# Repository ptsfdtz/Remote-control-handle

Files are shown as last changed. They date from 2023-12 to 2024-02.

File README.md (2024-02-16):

# Remote-control-handle

基于 nRF24L01 模块的远距离通讯以及遥控

## 1. 项目介绍

本项目是 2.4G 远距离遥控器的制作，基于 `Arduino` 框架开发

模型使用的是`soildworks`制作。

## 2. 项目结构

- **code** 代码
- **lib** 库
- **part** 模型部件
- **assembly** 模型装配体
- **stl** 打印模型

## 3. 模型介绍

模型灵感来源于在 Youtube 上看到一位博主自制的遥控器，比较感兴趣，所以参考了一下他的模型

有兴趣的可以去看一看这个视频，链接如下

[Making a 2400 meters LONG RANGE 8-Channel & Digital Trim Radio Control For RC Models](https://www.youtube.com/watch?v=RSDfMaanKXM&list=WL)

### 3.1 模型设计思路

为了更加贴切于航模遥控器和满足人体工程学，制作的还是最简单的盒子式的遥控器。

也是为了方便后期电路的布局不允许正常布线，模型制作的比较简单。

应各位同仁爱好，使用主题颜色使用的粉色和灰色，更加符合我们技术部的猛男特色。

### 3.2 模型视图

- #### 整体视图

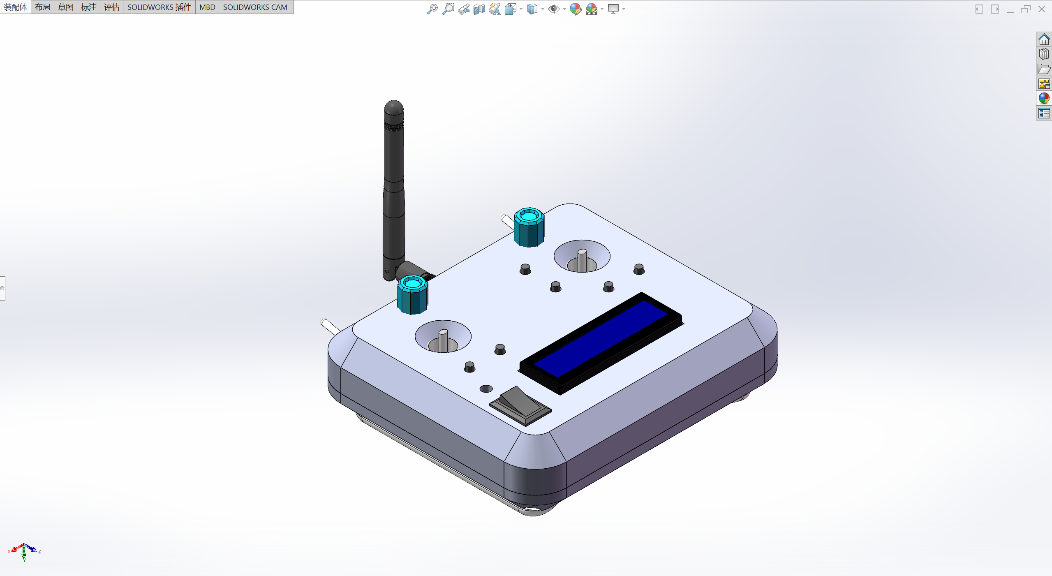
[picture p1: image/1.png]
整体视图


- #### 正面视图

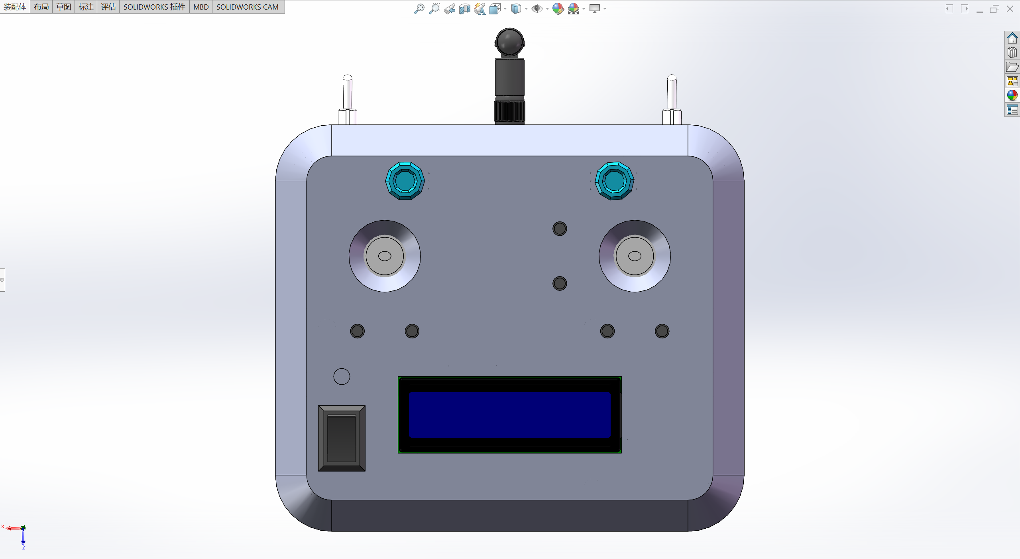
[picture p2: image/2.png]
正面视图


- #### 背面视图（透视）

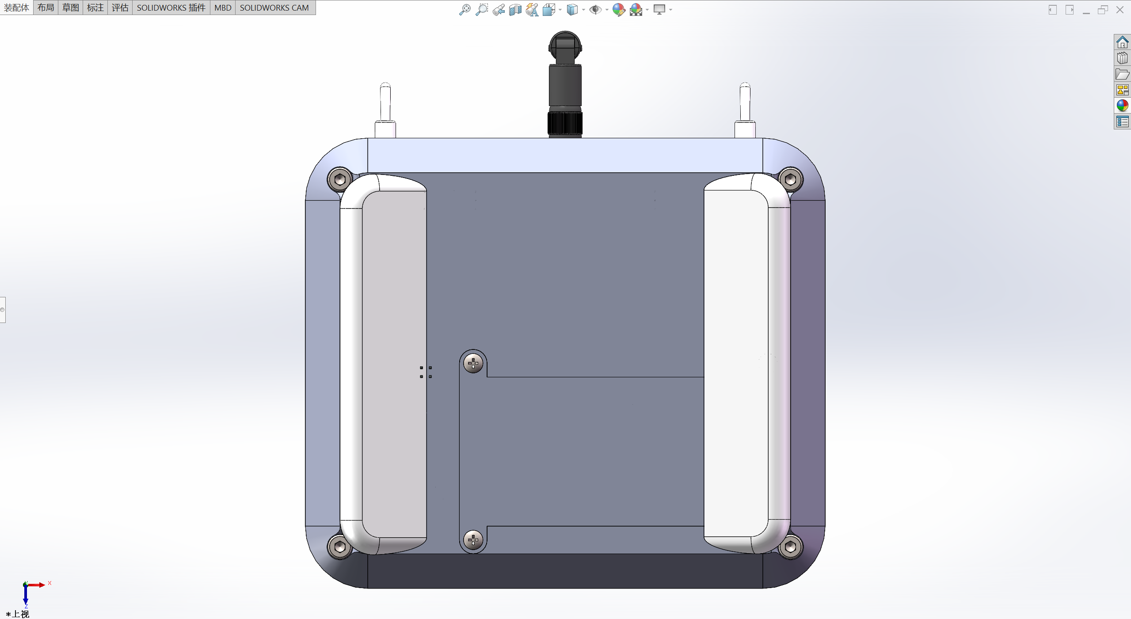
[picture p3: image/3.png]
背面视图（透视）


以上三种视图展示了模型整体的结构和各个原件的布局

### 3.3 模型爆炸视图

https://github.com/ptsfdtz/Remote-control-handle/assets/148436840/ea57b409-a363-41d5-a612-20af8ce92d28

展示拆分细节

## 4. 电路部分

### 4.1 模块介绍

- `EC11B15244 编码器`
- `KCD1-A 船型开关`
- `LCD1602 with I2C 显示屏`
- `MTS-10x-A2 微型切换开关`
- `XBOX360 线性可按压摇杆`
- `NRF24+SMA 无线接收器`

#### 4.1.1 EC11B15244 编码器

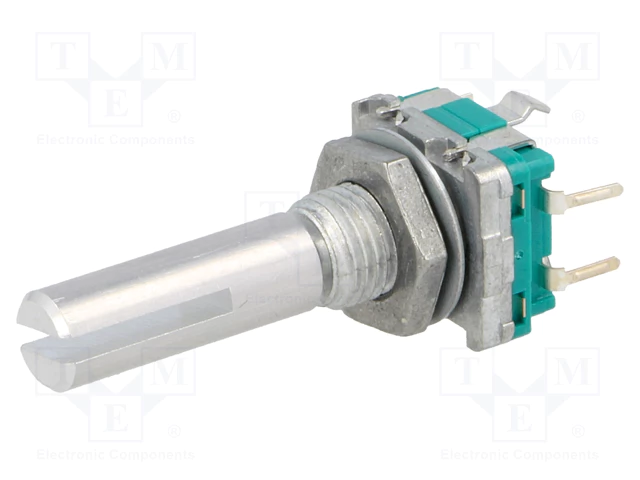
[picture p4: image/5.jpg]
EC11B15244


使用`EC11B15244`旋转编码器的案例通常涉及到读取旋转位置或旋转步数，主要用于位置检测，旋转方向检测，运动速度检测，步数计数，用户界面控制，电子设备调节。

在本项目中我们只使用到了其中的一部分功能。

下面是使用 arduino 的示例代码，使用`EC11B15244`需要连接电源以及输出引脚连接单片机的输入引脚，使用两个中断引脚连接到编码器的两个输出引脚，实现了在旋转时的位置计数。

```cpp
const int encoderPinA = 2;
const int encoderPinB = 3;

volatile long encoderPosition = 0;

void setup() {
  pinMode(encoderPinA, INPUT);
  pinMode(encoderPinB, INPUT);

  digitalWrite(encoderPinA, HIGH);
  digitalWrite(encoderPinB, HIGH);
  attachInterrupt(digitalPinToInterrupt(encoderPinA), updateEncoder, CHANGE);
  attachInterrupt(digitalPinToInterrupt(encoderPinB), updateEncoder, CHANGE);
  Serial.begin(9600);
}

void loop() {
  long newPosition = encoderPosition;
  if (newPosition != encoderPosition) {
    Serial.println(newPosition);
    encoderPosition = newPosition;
  }
}

void updateEncoder() {
  static byte encoder_A_prev = 0;

  byte encoder_A = digitalRead(encoderPinA);
  byte encoder_B = digitalRead(encoderPinB);

  if ((encoder_A == HIGH) && (encoder_A_prev == LOW)) {
    if (encoder_B == LOW) {
      encoderPosition++;
    } else {
      encoderPosition--;
    }
  }

  encoder_A_prev = encoder_A;
}

```

但是由于我们使用的单片机为 arduino nano，仅有两个中断引脚，所以不得不更换为电位器

电位器就是可调电阻，使用时可形成不同的分压

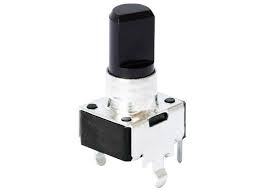
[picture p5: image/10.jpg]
电位器


在代码中可以调整电位器值转换为角度范围，使用`map`函数实现，示例代码如下，通过数字引脚输入信号读取电位器的转动角度。

```cpp
const int potPin_L = A0;
const int potPin_R = A1;
void setup() {
  Serial.begin(9600);
}

void loop() {
  int potValue_L = analogRead(potPin_L);
  int potValue_R = analogRead(potPin_R);

  int angle_L = map(potValue_L, 0, 1023, 0, 360);
  int angle_R = map(potValue_R, 0, 1023, 0, 360);

  Serial.println(angle_L);
  Serial.println(angle_R);

  delay(100);
}
```

#### 4.1.2 LCD1602 with I2C

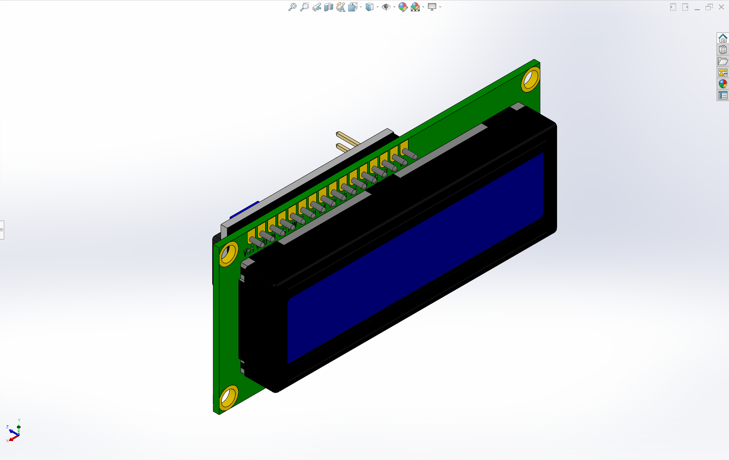
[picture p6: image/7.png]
KCD1-A


`i2c通讯`原理可以详见电子组培训文档[电子组培训文档-i2c 通讯原理](https://book.jinhun.moe/MCU-Communication/Serial/I2C/Intro.html)

在本项目中屏幕的主要功能是模式选择以及显示此刻遥控器的指令，以便于后期调试和用户的交互式体验。

我使用的是`LiquidCrystal`库[介绍文档](https://www.arduino.cc/reference/en/libraries/liquidcrystal/)

该库允许 Arduino 板控制基于 Hitachi HD44780（或兼容）芯片组的液晶显示器（LCD），该芯片组在大多数基于文本的 LCD 上都可以找到。

下面是示例代码，需要连接单片的的`SDA`和`SCL`引脚，使用 3.3v/5v 供电。

```cpp
#include <Wire.h>
#include <LiquidCrystal_I2C.h>

#define LCD_ADDRESS 0x27
#define LCD_COLUMNS 16
#define LCD_ROWS 2

LiquidCrystal_I2C lcd(LCD_ADDRESS, LCD_COLUMNS, LCD_ROWS);

void setup() {
  lcd.begin();
  lcd.print("Hello World");
}

void loop() {
  // 在loop中可以添加其他代码
}
```

#### 4.1.3 nRF24L01

我使用的是`nRF24L01+PA/LNA`的版本，除了天线外，它还有一个 RFX2401C 芯片，包括 PA（功率放大器）和 LNA（低噪声放大器）。 放大了 NRF24L01 信号，并在开放空间中实现了长达 1000 米的更好传输范围。

该模块可以使用 `125` 个不同的通道，从而可以在一个地方拥有 125 个独立工作的调制解调器网络。每个通道最多可以有 6 个地址，或者每个单元最多可以同时与 6 个其他单元通信,也就是说该模块可以同时控制其他六个设备。

以下是`NRF24L01`引脚排列以及 `NRF24L01+ PA/LNA` 模块的详细介绍。

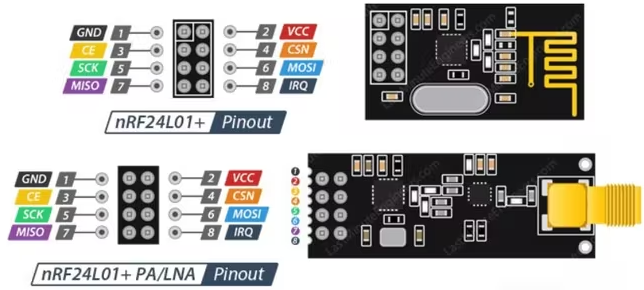
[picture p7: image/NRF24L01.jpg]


##### **下面分别为接收端和发射端的接线图**

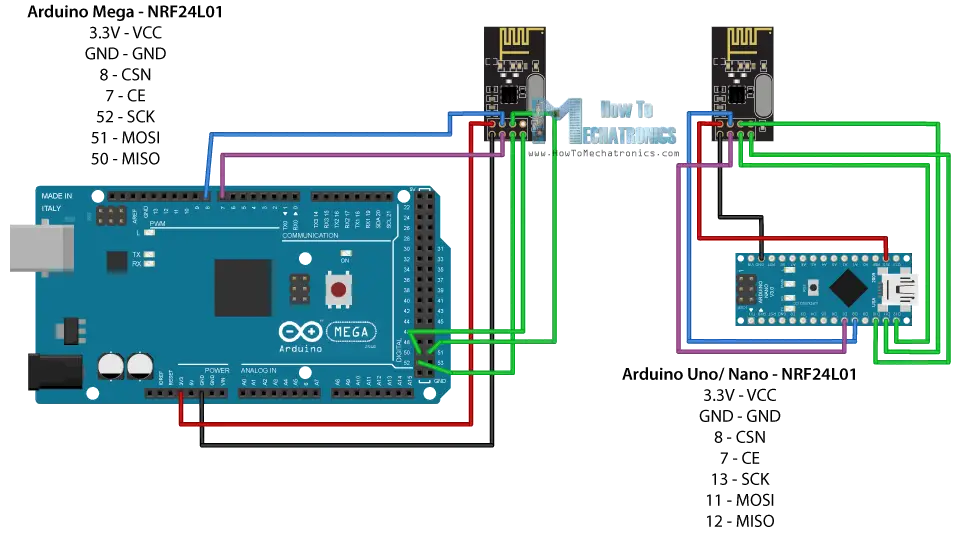
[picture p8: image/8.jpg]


**发射端示例代码**

```cpp
#include <SPI.h>
#include <nRF24L01.h>
#include <RF24.h>

RF24 radio(7, 8); // CE, CSN

const byte address[6] = "00001";

void setup() {
  radio.begin();
  radio.openWritingPipe(address);
  radio.setPALevel(RF24_PA_MIN);
  radio.stopListening();
}

void loop() {
  const char text[] = "Hello World";
  radio.write(&text, sizeof(text));
  delay(1000);
}
```

**接收端示例代码**

```cpp
#include <SPI.h>
#include <nRF24L01.h>
#include <RF24.h>

RF24 radio(7, 8); // CE, CSN

const byte address[6] = "00001";

void setup() {
  Serial.begin(9600);
  radio.begin();
  radio.openReadingPipe(0, address);
  radio.setPALevel(RF24_PA_MIN);
  radio.startListening();
}

void loop() {
  if (radio.available()) {
    char text[32] = "";
    radio.read(&text, sizeof(text));
    Serial.println(text);
  }
}
```

**问题简介**

电源噪声是与 NRF24L01 模块成功通信时遇到的最常见问题之一。射频电路或射频信号对电源噪声很敏感。在电源线上加入一个**去耦电容**可以适当解决。电容器可以是 10uF 到 100uF 之间的任何值。

另一个问题是 Arduino 板的 3.3V 引脚不能始终为 NRF24L01 模块提供足够的电源。因此，也可以使用外部电源。

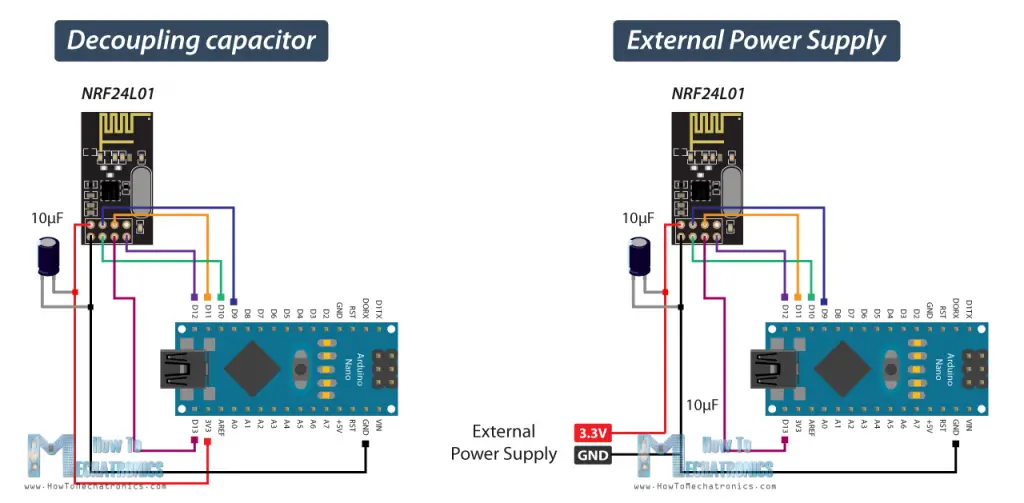
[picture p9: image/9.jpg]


#### 4.1.4 线性按键摇杆

`ps2`手柄上的可按压摇杆使用非常的广泛而且十分的简便，无需安装其他库。

并且仅用一只手指即可以完成三种信号的输出，可操作性比其他的摇杆优势高。

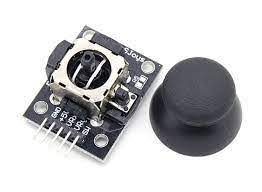
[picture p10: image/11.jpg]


`vRX`和`vRy`需要连接在模拟输入口，示例代码如下。

```cpp
const int xPin1 = A7;
const int yPin1 = A6;
const int buttonPin1 = 0;

const int xPin2 = A3;
const int yPin2 = A2;
const int buttonPin2 = 1;

void setup() {
  Serial.begin(9600);
  pinMode(xPin1, INPUT);
  pinMode(yPin1, INPUT);
  pinMode(buttonPin1, INPUT_PULLUP);

  pinMode(xPin2, INPUT);
  pinMode(yPin2, INPUT);
  pinMode(buttonPin2, INPUT_PULLUP);
}

void loop() {
  int xValue1 = analogRead(xPin1);
  int yValue1 = analogRead(yPin1);
  int buttonState1 = digitalRead(buttonPin1);

  int xValue2 = analogRead(xPin2);
  int yValue2 = analogRead(yPin2);
  int buttonState2 = digitalRead(buttonPin2);

  Serial.print(xPin1);
  Serial.print(" ");
  Serial.print(yPin1);
  Serial.print(" ");
  Serial.print(buttonPin1);
  Serial.print(" ");
  Serial.print(xPin2);
  Serial.print(" ");
  Serial.print(yPin2);
  Serial.print(" ");
  Serial.println(buttonPin2);
  delay(100);
}
```

## 5. 功能简介

### **实物视图**

- 正面视图

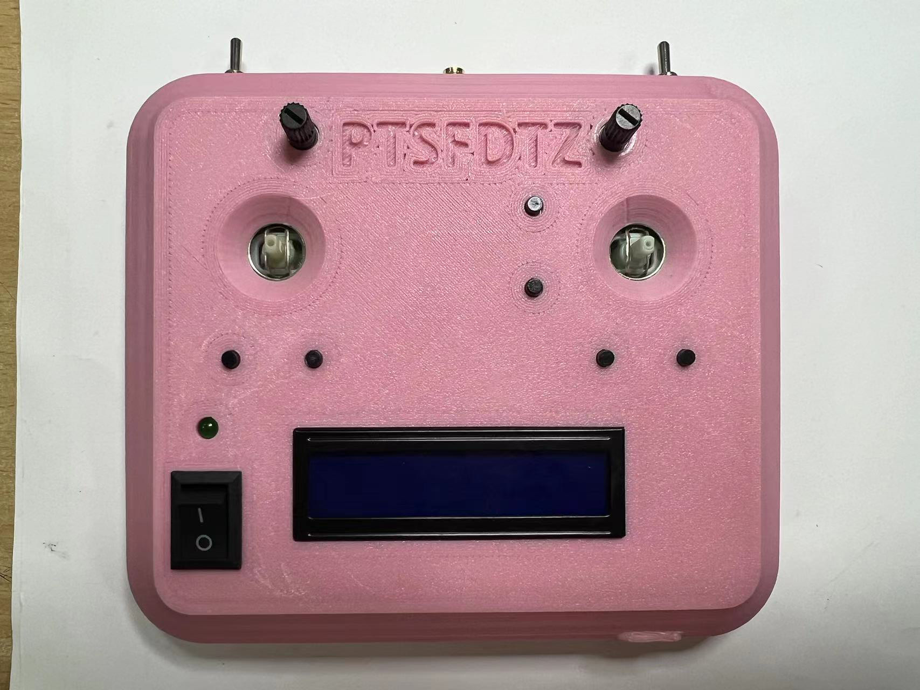
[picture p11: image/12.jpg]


- 背面视图（忽略我粗糙的理线）

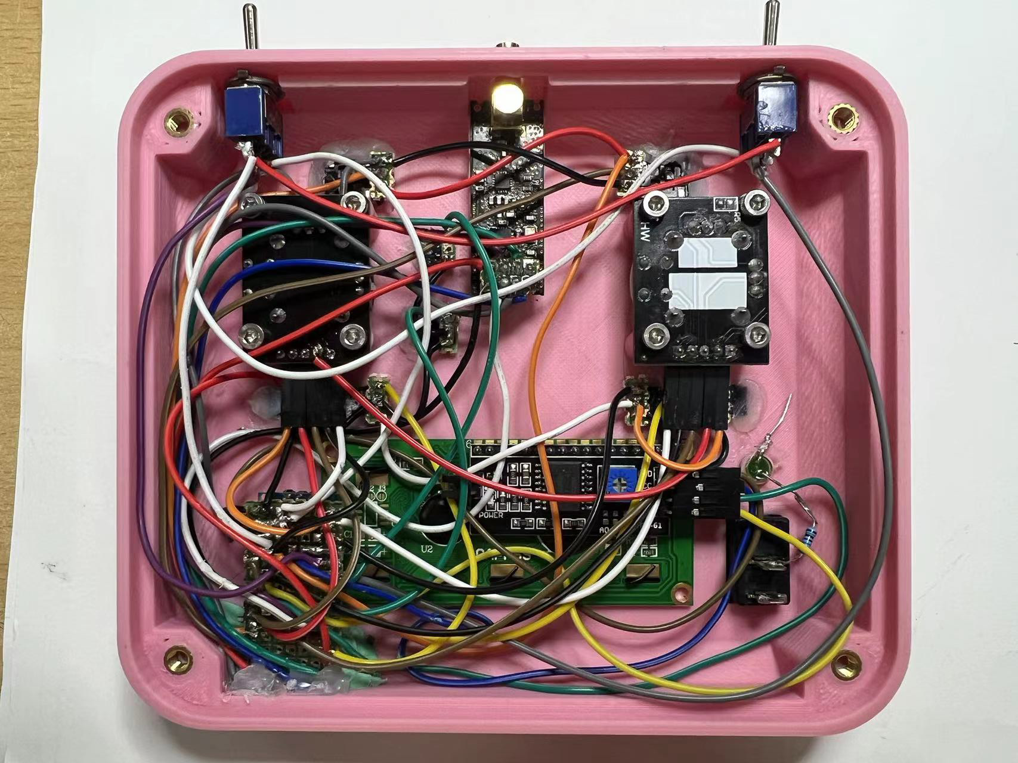
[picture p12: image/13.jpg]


### **视频展示**

https://github.com/ptsfdtz/Remote-control-handle/assets/148436840/af519cdb-0244-4dc7-bf22-2b7f280e0448

制作了调试功能分别有三种模式：

1. 打开右上角开关：按键功能检测，左侧两个为`reset`和功能键，右侧为四个功能键，初期打算这五个按键作为通道以及功能选择来使用。

2. 打开左上角开关：线性手柄功能检测，左右两个手柄的 XY 轴数值会显示在 LCD 屏幕上。

3. 打开左右开关：电位器功能检测，LCD 屏幕上会显示电位器的转动角度，后期打算作为舵机精准控制使用。

## 更新内容

由于上一代版本理线过于混乱，所以我绘制了一个简单的 PCB 拓展板

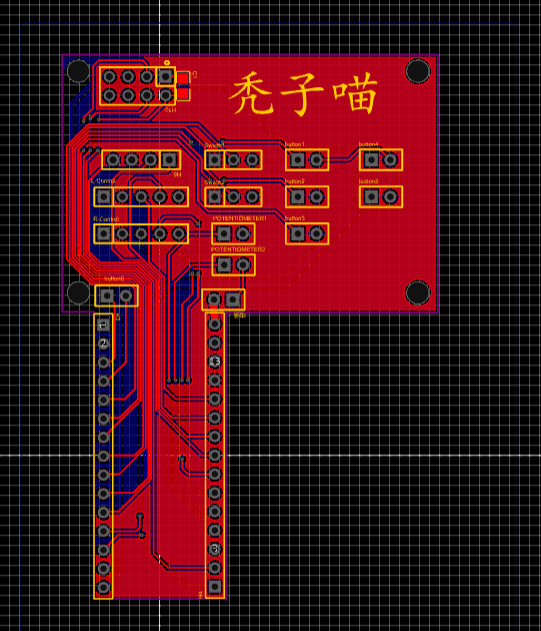
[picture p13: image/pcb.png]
PCB拓展板


并且更新了模型，下面的想法是不使用 18650 电池供电，增加一个锂电池和充电功能。

因为目前整个模型内部空间非常的紧张。

## 更新 ing

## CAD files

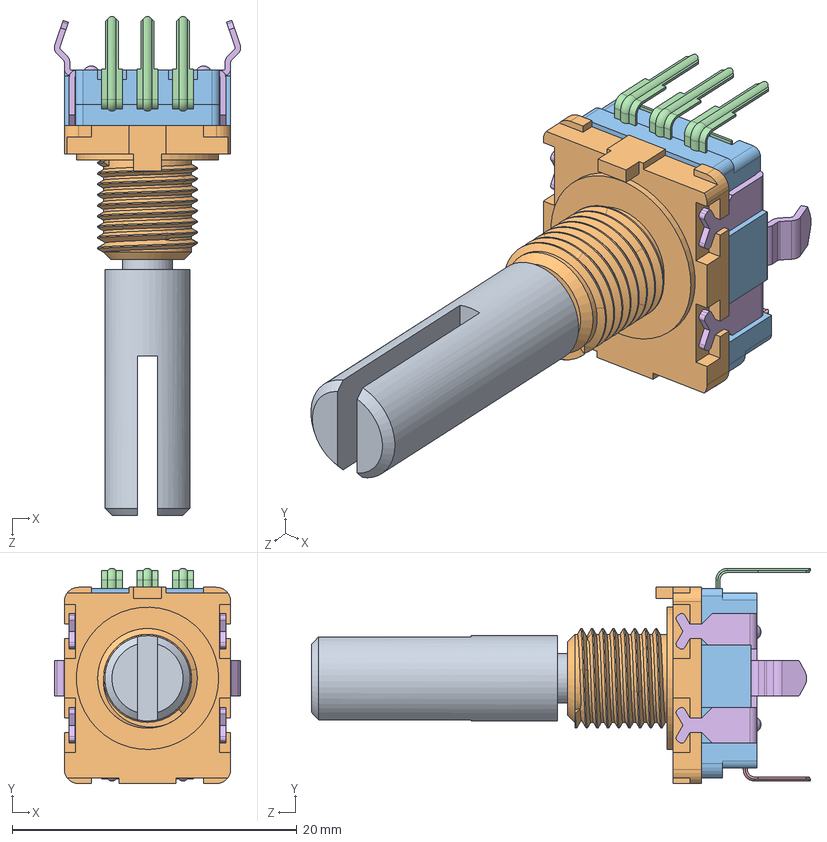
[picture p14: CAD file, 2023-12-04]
part/EC11B15244/User Library-EC11B15244.sldasm
13.1 x 15.1 x 35.1 mm
User Library-EC11B15244_Shaft
User Library-EC11B15244_MetalBody
User Library-EC11B15244_PlasticBody
User Library-EC11B15244_Imported x 3
User Library-EC11B15244_Pin x 2
User Library-EC11B15244_Sheet Metal Part53

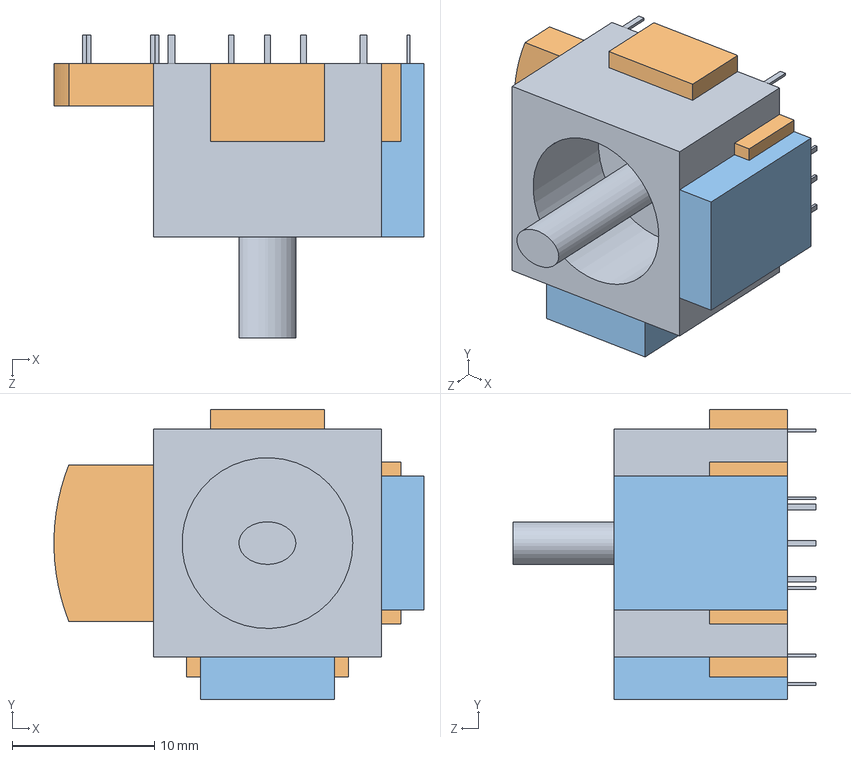
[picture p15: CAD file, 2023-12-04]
part/XBOX360/User Library-XBOX360.sldasm
26.0 x 20.4 x 21.3 mm
User Library-XBOX360_Fusion001
User Library-XBOX360_Fusion
User Library-XBOX360_black

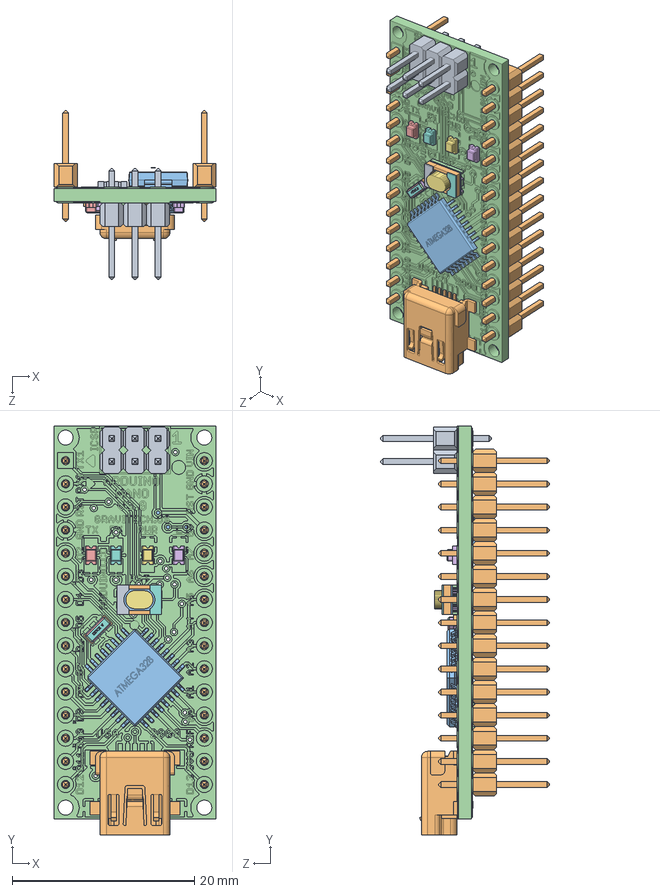
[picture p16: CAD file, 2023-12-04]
part/Nano-1/User Library-Nano-1.sldasm
17.8 x 44.9 x 18.6 mm
User Library-Nano-1_Nano.sldasm-Part-1
User Library-Nano-1_User Library-Arduino Nano 3.0_HDR1x15 x 2
User Library-Nano-1_User Library-Arduino Nano 3.0_SOT-223
User Library-Nano-1_User Library-Arduino Nano 3.0_User Library-SSOP-28-FT232RL_
User Library-Nano-1_Nano.sldasm-Part-2
User Library-Nano-1_Nano.sldasm-Part-3
User Library-Nano-1_Nano.sldasm-Part-4
User Library-Nano-1_Nano.sldasm-Part-5
User Library-Nano-1_User Library-Arduino Nano 3.0_HDR2x3
User Library-Nano-1_NONE
User Library-Nano-1_User Library-Arduino Nano 3.0_User Library-SW3dPS-atmega8 (tqfp32)_V2008_
User Library-Nano-1_Nano.sldasm-Part-6
User Library-Nano-1_User Library-CSTCE_V-1_Board1
User Library-Nano-1_User Library-LS8_Board_1
User Library-Nano-1_User Library-CSTCE_V-1_Extruded20
User Library-Nano-1_User Library-CSTCE_V-1_Extruded15
User Library-Nano-1_User Library-CSTCE_V-1_Extruded14 x 2
User Library-Nano-1_User Library-CSTCE_V-1_Extruded17
User Library-Nano-1_User Library-CSTCE_V-1_Extruded21
User Library-Nano-1_User Library-CSTCE_V-1_Extruded25
User Library-Nano-1_User Library-CSTCE_V-1_Extruded23
User Library-Nano-1_User Library-CSTCE_V-1_Extruded18 x 2
User Library-Nano-1_User Library-CSTCE_V-1_Extruded16
User Library-Nano-1_User Library-CSTCE_V-1_Extruded13
User Library-Nano-1_User Library-CSTCE_V-1_Extruded24 x 2
User Library-Nano-1_User Library-CSTCE_V-1_Extruded22 x 2
User Library-Nano-1_User Library-CSTCE_V-1_Sphere1 x 4
User Library-Nano-1_User Library-CSTCE_V-1_Cylinder3 x 2
User Library-Nano-1_User Library-CSTCE_V-1_Cylinder2 x 2
User Library-Nano-1_User Library-CSTCE_V-1_Extruded19
User Library-Nano-1_User Library-LS8_Extruded_9
User Library-Nano-1_User Library-LS8_Extruded_10
User Library-Nano-1_User Library-LS8_Extruded_11
User Library-Nano-1_User Library-LS8_Extruded_12
User Library-Nano-1_User Library-LS8_Extruded_13
User Library-Nano-1_User Library-LS8_Extruded_14
User Library-Nano-1_User Library-LS8_Extruded_15
User Library-Nano-1_User Library-LS8_Extruded_16 x 2
User Library-Nano-1_User Library-LS8_Extruded_17 x 2

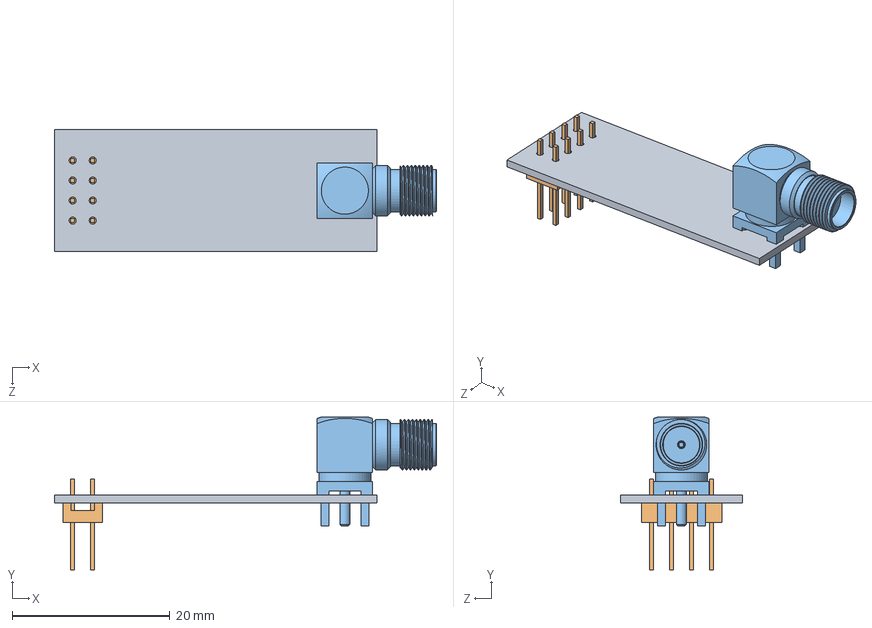
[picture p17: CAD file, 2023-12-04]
part/NRF24+SMA/User Library-NRF24+SMA.SLDASM
48.4 x 19.4 x 15.4 mm
User Library-NRF24+SMA_plata
User Library-NRF24+SMA_User Library-PLD-8
User Library-NRF24+SMA_6RFX

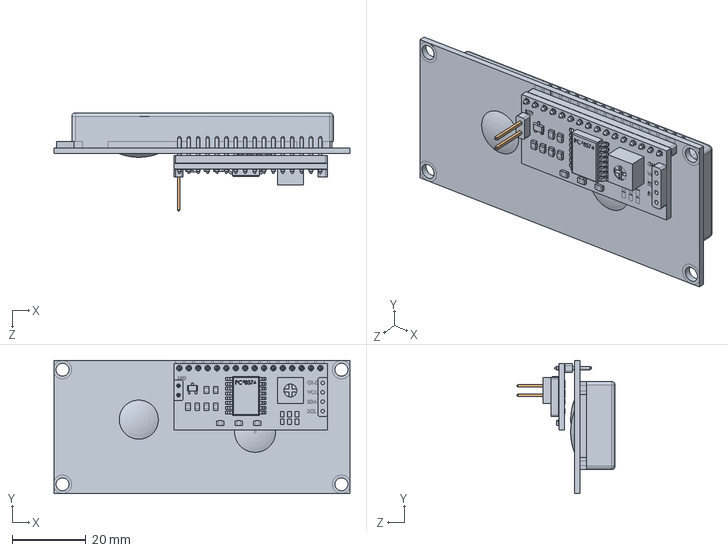
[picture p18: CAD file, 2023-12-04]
part/LCD1602 with I2C/User Library-LCD1602 with I2C.SLDASM
80.0 x 36.0 x 26.6 mm
User Library-LCD1602 with I2C_Imported
User Library-LCD1602 with I2C_pin x 2

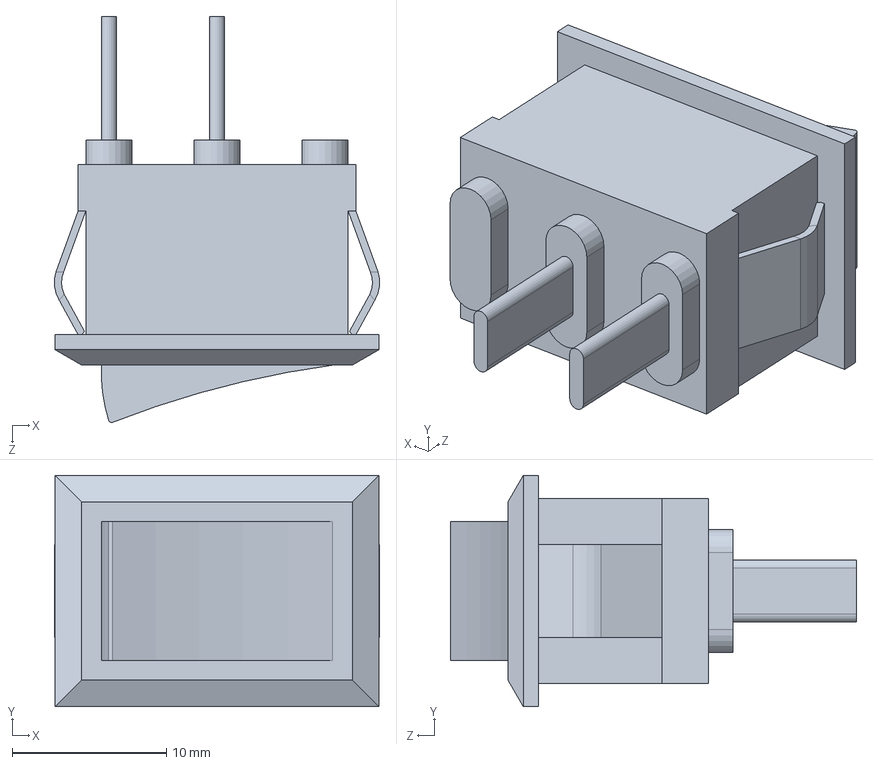
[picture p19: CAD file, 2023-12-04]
part/KCD1-A/User Library-KCD1-A.sldprt
21.1 x 15.0 x 26.3 mm

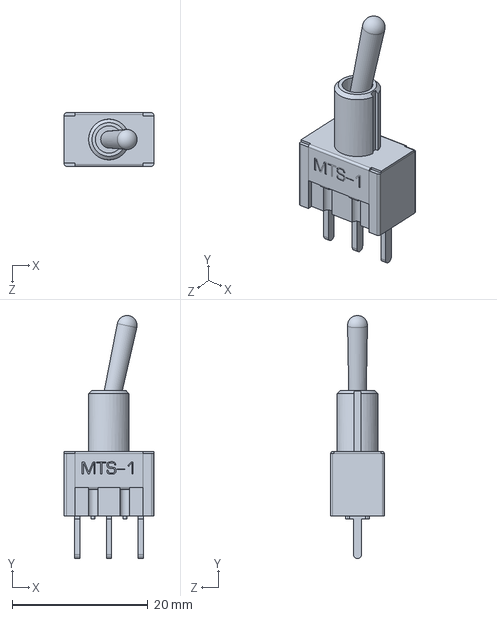
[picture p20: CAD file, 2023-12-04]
part/MTS-10x-A2/User Library-MTS-10x-A2.sldprt
13.2 x 35.8 x 7.90 mm

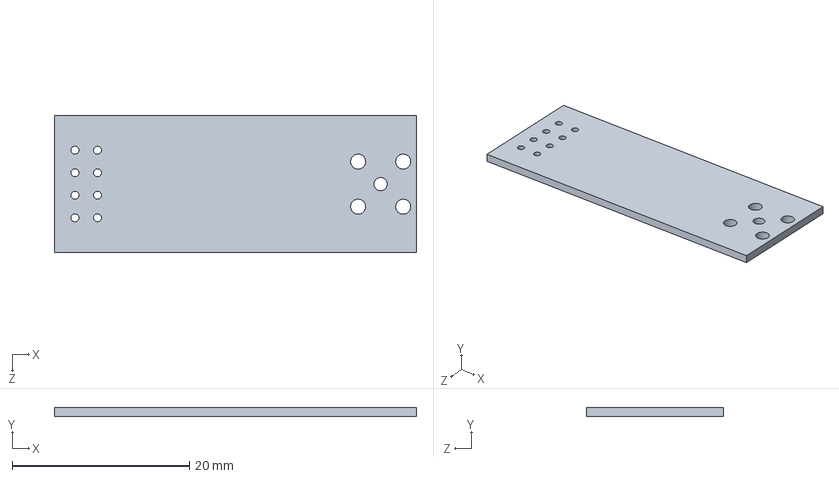
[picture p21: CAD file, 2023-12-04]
part/NRF24+SMA/User Library-NRF24+SMA_plata.SLDPRT
40.8 x 1.00 x 15.4 mm

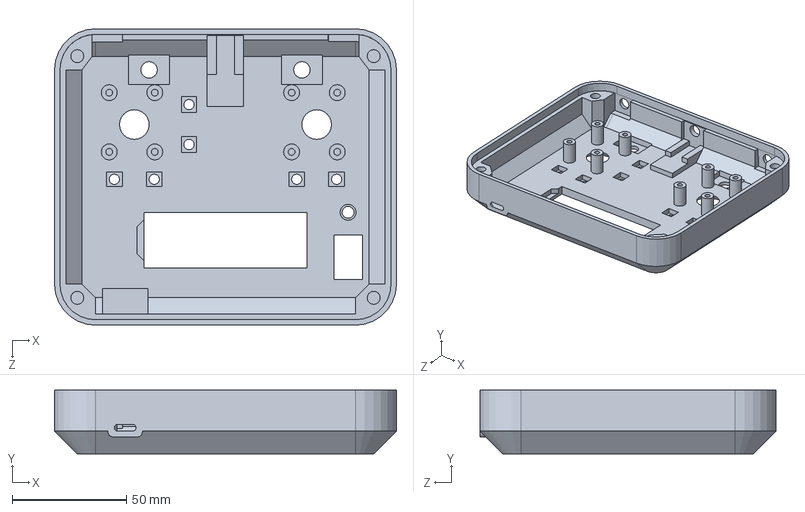
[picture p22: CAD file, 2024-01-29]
part/panel.SLDPRT
150.0 x 28.0 x 130.0 mm

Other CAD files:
part/EC11B15244/User Library-EC11B15244_Pins.sldasm
part/LCD1602 with I2C/User Library-LCD1602 with I2C_User Library-1x4 TH Pitch 2_54mm.SLDASM
part/Nano-1/User Library-Nano-1_Nano.sldasm-Part-3.sldprt
part/Nano-1/User Library-Nano-1_Nano.sldasm-Part-4.sldprt
part/Nano-1/User Library-Nano-1_Nano.sldasm-Part-2.sldprt
part/Nano-1/User Library-Nano-1_Nano.sldasm-Part-1.sldprt
part/Nano-1/User Library-Nano-1_Nano.sldasm-Part-5.sldprt
part/LCD1602 with I2C/User Library-LCD1602 with I2C_holder.SLDPRT
part/Nano-1/User Library-Nano-1_User Library-CSTCE_V-1_Extruded24.sldprt
part/Backplate.SLDPRT
part/Battery backplane.SLDPRT
part/Battery-compartment.SLDPRT
part/EC11B15244/User Library-EC11B15244_Imported.sldprt
part/EC11B15244/User Library-EC11B15244_MetalBody.sldprt
part/EC11B15244/User Library-EC11B15244_Pin.sldprt
part/EC11B15244/User Library-EC11B15244_PlasticBody.sldprt
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

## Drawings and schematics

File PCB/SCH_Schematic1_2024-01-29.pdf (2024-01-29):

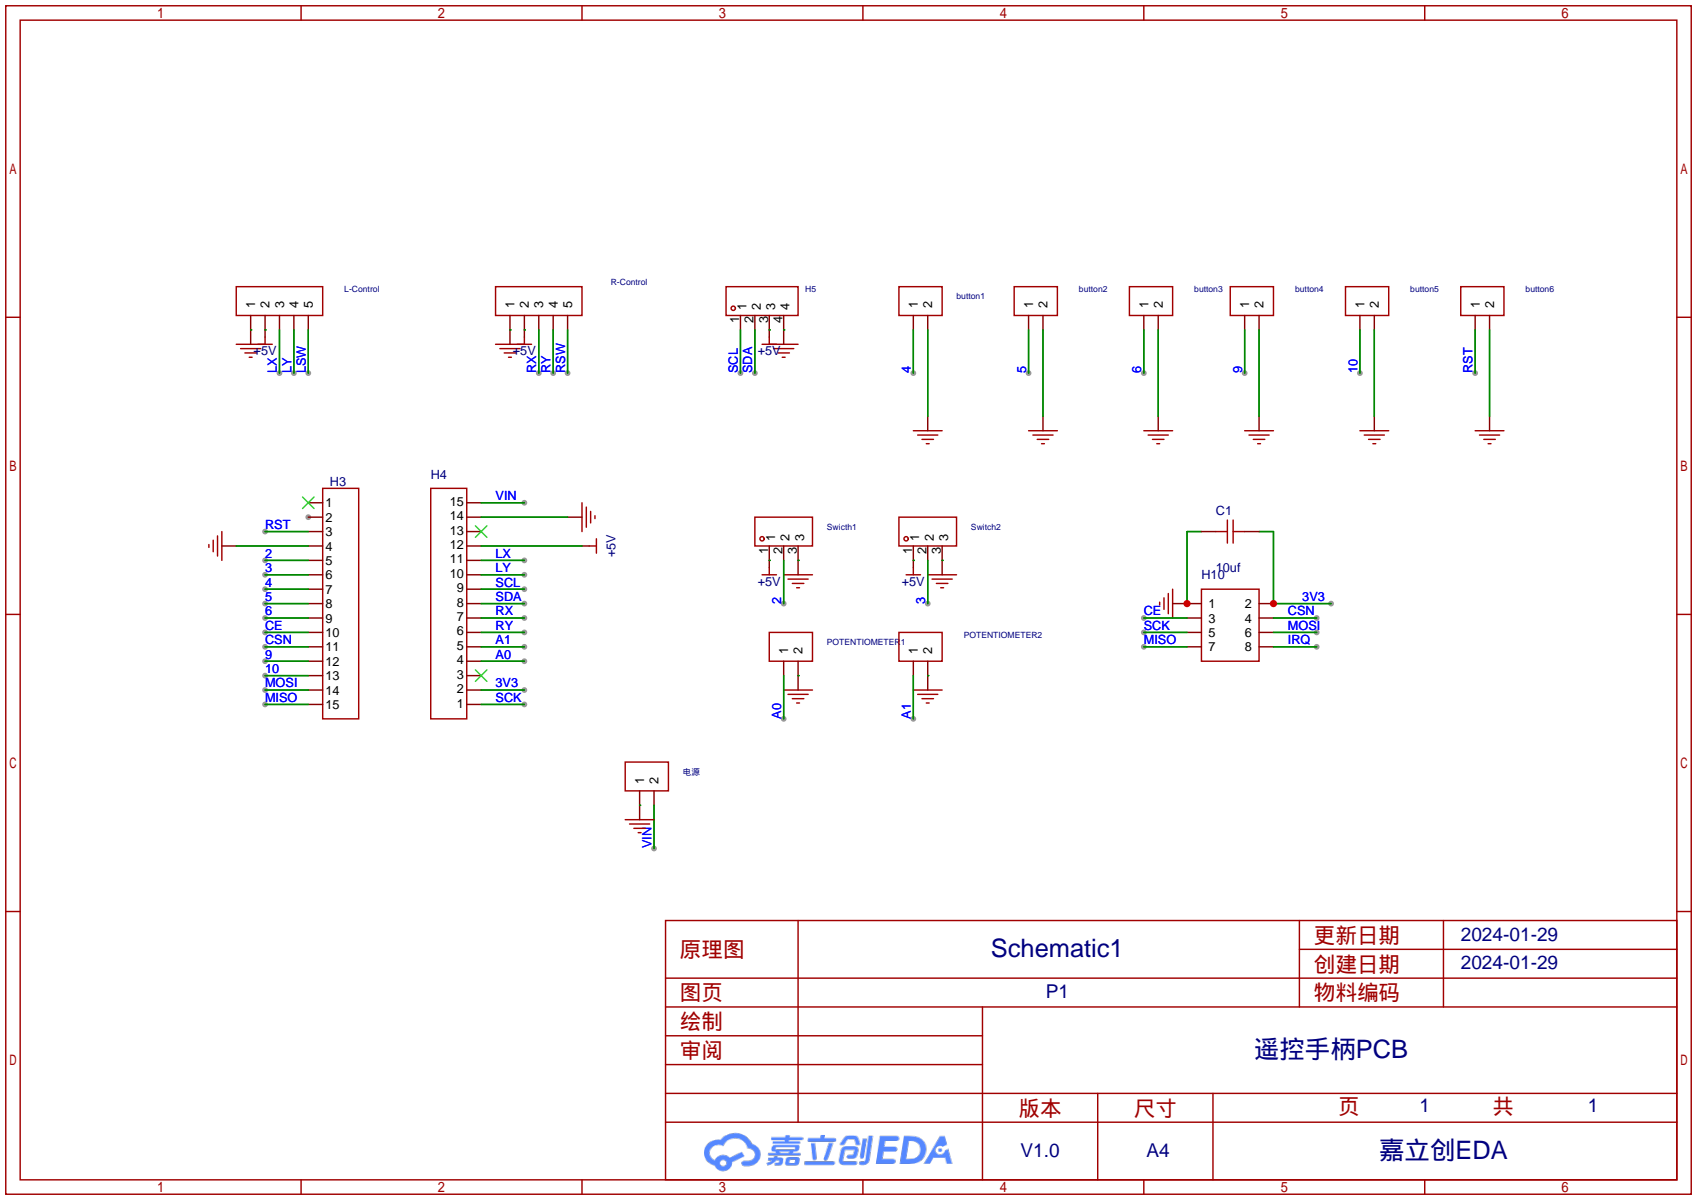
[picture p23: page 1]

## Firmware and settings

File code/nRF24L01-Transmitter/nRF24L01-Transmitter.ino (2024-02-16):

#include <Wire.h>
#include <LiquidCrystal_I2C.h>
#include <SPI.h>
#include <nRF24L01.h>
#include <RF24.h>

#define LCD_ADDRESS 0x27
#define LCD_COLUMNS 16
#define LCD_ROWS 2

RF24 radio(7, 8);
const byte address[6] = "00001";

struct ControlMessage {
  int xValue_R;
  int yValue_R;
  int xValue_L;
  int yValue_L;
  int speed;
  int angle_L;
  int angle_R;
};

const int buttonPins[] = {4, 5, 6, 9, 10};
const int switchPins[] = {2, 3};
const int analogPinsL[] = {A7, A6, 0, A0};
const int analogPinsR[] = {A3, A2, 1, A1};

LiquidCrystal_I2C lcd(LCD_ADDRESS, LCD_COLUMNS, LCD_ROWS);

void sendControlMessage(int xValue_R, int yValue_R, int xValue_L, int yValue_L, int speed, int angle_L, int angle_R) {
  ControlMessage controlMessage;
  controlMessage.xValue_R = xValue_R;
  controlMessage.yValue_R = yValue_R;
  controlMessage.xValue_L = xValue_L;
  controlMessage.yValue_L = yValue_L;
  controlMessage.speed = speed;
  controlMessage.angle_L = angle_L;
  controlMessage.angle_R = angle_R;

  radio.write(&controlMessage, sizeof(controlMessage));
}

void setup() {
  Serial.begin(9600);
  radio.begin();
  radio.openWritingPipe(address);
  radio.setPALevel(RF24_PA_MIN);
  radio.stopListening();

  for (int pin : buttonPins)
    pinMode(pin, INPUT_PULLUP);

  for (int pin : switchPins)
    pinMode(pin, INPUT_PULLUP);

  for (int pin : analogPinsL)
    pinMode(pin, INPUT);

  for (int pin : analogPinsR)
    pinMode(pin, INPUT);

  begin_cartoon();
}

void loop() {
  int state[5];
  int xValue_L, yValue_L, buttonValue_L, xValue_R, yValue_R, buttonValue_R, potValue_L, potValue_R, angle_L, angle_R;

  for (int i = 0; i < 5; ++i)
    state[i] = digitalRead(buttonPins[i]);

  xValue_L = analogRead(analogPinsL[0]);
  yValue_L = analogRead(analogPinsL[1]);
  buttonValue_L = analogRead(analogPinsL[2]);

  xValue_R = analogRead(analogPinsR[0]);
  yValue_R = analogRead(analogPinsR[1]);
  buttonValue_R = analogRead(analogPinsR[2]);

  potValue_L = analogRead(analogPinsL[3]);
  potValue_R = analogRead(analogPinsR[3]);
  angle_L = map(potValue_L, 0, 1023, 0, 90);
  angle_R = map(potValue_R, 0, 1023, 0, 90);

  if (digitalRead(switchPins[0]) == HIGH && digitalRead(switchPins[1]) == LOW)
    show_bottom(state[0], state[1], state[2], state[3], state[4]);
  else if (digitalRead(switchPins[1]) == HIGH && digitalRead(switchPins[0]) == LOW)
    show_XYB(xValue_L, yValue_L, buttonValue_L, xValue_R, yValue_R, buttonValue_R);
  else if (digitalRead(switchPins[1]) == HIGH && digitalRead(switchPins[0]) == HIGH)
    show_angle(angle_L, angle_R);
  else
    show_direction(xValue_R, yValue_R, yValue_L, xValue_L, angle_L, angle_R);
}

void show_bottom(int state1, int state2, int state3, int state4, int state5) {
  show_lcd("Bottom Selection:", (String(state1) + " " + String(state2) + " " + String(state3) + " " + String(state4) + " " + String(state5)).c_str());
}

void show_XYB(int xValue_L, int yValue_L, int buttonValue_L, int xValue_R, int yValue_R, int buttonValue_R) {
  show_lcd("X Y Bottom value:", (String(xValue_L) + " " + String(yValue_L) + " " + String(xValue_R) + " " + String(yValue_R) + " " + String(buttonValue_L) + " " + String(buttonValue_R)).c_str());
}

void show_angle(int angle_L, int angle_R) {
  show_lcd("Potent angle:", (String(angle_L) + "       " + String(angle_R)).c_str());
}

void show_direction(int xValue_R, int yValue_R, int yValue_L, int xValue_L, int angle_L, int angle_R) {
  int speed;

  if (xValue_R > 550) {
    speed = xValue_R - 508;
    show_lcd("Direction speed", ("Forward   " + String(speed)).c_str());
  } else if (xValue_R < 480) {
    speed = 508 - xValue_R;
    show_lcd("Direction speed", ("Backward  " + String(speed)).c_str());
  } else if (yValue_R > 510) {
    speed = yValue_R - 508;
    show_lcd("Direction speed", ("Right     " + String(speed)).c_str());
  } else if (yValue_R < 506) {
    speed = 508 - yValue_R;
    show_lcd("Direction speed", ("Left      " + String(speed)).c_str());
  } else if (yValue_L > 518) {
    speed = yValue_L - 508;
    show_lcd("Direction speed", ("Shift_R   " + String(speed)).c_str());
  } else if (yValue_L < 510) {
    speed = 508 - yValue_L;
    show_lcd("Direction speed", ("Shift_L   " + String(speed)).c_str());
  } else if (xValue_L > 503) {
    speed = xValue_L - 499;
    show_lcd("Direction speed", ("L_up     " + String(speed)).c_str());
  } else if (xValue_L < 495) {
    speed = 499 - xValue_L;
    show_lcd("Direction speed", ("L_down     " + String(speed)).c_str());
  } else {
    speed = 0;
    show_lcd("Direction speed", ("Stop     " + String(speed)).c_str());
  }
  sendControlMessage(xValue_R, yValue_R, xValue_L, yValue_L, speed, angle_L, angle_R);
}

void show_lcd(const char *line1, const char *line2) {
  lcd.clear();
  lcd.setCursor(0, 0);
  lcd.print(line1);
  lcd.setCursor(0, 1);
  lcd.print(line2);
  delay(50);
}

void begin_cartoon() {
  lcd.begin(LCD_COLUMNS, LCD_ROWS);
  lcd.clear();
  for (int i = 0; i < LCD_COLUMNS; ++i) {
    lcd.setCursor(i, 0);
    lcd.print("$");
    lcd.setCursor(LCD_COLUMNS - i - 1, 1);
    lcd.print("$");
    delay(150);
  }
  delay(1000);
  lcd.clear();
  lcd.setCursor(0, 0);
  lcd.print("  Welcome to");
  lcd.setCursor(0, 1);
  lcd.print("  Your Device");
}

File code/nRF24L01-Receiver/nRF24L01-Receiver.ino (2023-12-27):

#include <SPI.h>
#include <nRF24L01.h>
#include <RF24.h>
#include "Motor.h"
#include <Servo.h>
Servo servo1;  // 创建一个Servo对象来控制第一个舵机
Servo servo2;  // 创建一个Servo对象来控制第二个舵机
struct ControlMessage {
  int xValue_R;
  int yValue_R;
  int xValue_L;
  int yValue_L;
  int speed;
  int angle_L;
  int angle_R;
};
int angle1;
int angle2;
int speed;
RF24 radio(7, 8);  // CE, CSN
Motor motor(22, 24, 28, 26, 30, 32, 36, 34, 2, 3, 4, 5);

const byte address[6] = "00001";
unsigned long lastReceiveTime = 0;
const unsigned long timeoutPeriod = 1000;  // Set your desired timeout period in milliseconds

void setup() {
  Serial.begin(9600);
  servo1.attach(9);
  servo2.attach(10);
  radio.begin();
  radio.openReadingPipe(0, address);
  radio.setPALevel(RF24_PA_MIN);
  radio.startListening();
  servo_begin();
}

void loop() {
  if (radio.available()) {
    ControlMessage receivedMessage;
    radio.read(&receivedMessage, sizeof(receivedMessage));
    lastReceiveTime = millis();  // Update last receive time
    servo1.write(receivedMessage.angle_L);
    servo2.write(receivedMessage.angle_R);
    if (receivedMessage.speed > 500) {
      speed = 250;
    } else {
      speed = receivedMessage.speed / 2;
    }

    if (receivedMessage.xValue_R > 550) {
      motor.speed(speed);
      motor.forward();
    } else if (receivedMessage.xValue_R < 480) {
      motor.speed(speed);
      motor.backward();
    } else if (receivedMessage.yValue_R > 550) {
      motor.speed(speed);
      motor.horizontal_L();
    } else if (receivedMessage.yValue_R < 480) {
      motor.speed(speed);
      motor.horizontal_R();
    } else {
      motor.speed(0);
      motor.stop();
    }

    if (receivedMessage.xValue_L > 550) {
      
    } else if (receivedMessage.xValue_L < 480) {

    } else if (receivedMessage.yValue_L > 530) {
      motor.speed(speed/2);
      motor.right();
    } else if (receivedMessage.yValue_L < 500) {
      motor.speed(speed/2);
      motor.left();
    } 
  }

  if (millis() - lastReceiveTime > timeoutPeriod) {
    motor.speed(0);
    motor.stop();
  }
}

void servo_begin(){
  servo1.write(0);
  servo2.write(0);
}

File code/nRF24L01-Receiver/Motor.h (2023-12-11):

class Motor {
private:
  int L1_IN1;
  int L1_IN2;
  int R1_IN1;
  int R1_IN2;
  int L2_IN1;
  int L2_IN2;
  int R2_IN1;
  int R2_IN2;
  int M1_Speed;
  int M2_Speed;
  int M3_Speed;
  int M4_Speed;

public:
  Motor(int l1_in1, int l1_in2, int r1_in1, int r1_in2, int l2_in1, int l2_in2, int r2_in1, int r2_in2, int m1_speed, int m2_speed, int m3_speed, int m4_speed) {
    L1_IN1 = l1_in1;
    L1_IN2 = l1_in2;
    R1_IN1 = r1_in1;
    R1_IN2 = r1_in2;
    L2_IN1 = l2_in1;
    L2_IN2 = l2_in2;
    R2_IN1 = r2_in1;
    R2_IN2 = r2_in2;
    M1_Speed = m1_speed;
    M2_Speed = m2_speed;
    M3_Speed = m3_speed;
    M4_Speed = m4_speed;
    pinMode(L1_IN1, OUTPUT);
    pinMode(L1_IN2, OUTPUT);
    pinMode(R1_IN1, OUTPUT);
    pinMode(R1_IN2, OUTPUT);
    pinMode(L2_IN1, OUTPUT);
    pinMode(L2_IN2, OUTPUT);
    pinMode(R2_IN1, OUTPUT);
    pinMode(R2_IN2, OUTPUT);
    pinMode(M1_Speed, OUTPUT);
    pinMode(M2_Speed, OUTPUT);
    pinMode(M3_Speed, OUTPUT);
    pinMode(M4_Speed, OUTPUT);
  }

  void speed(int speed) {
    analogWrite(M1_Speed, speed);  //控制电机的速度，不同的车模，代码执行效果不同！
    analogWrite(M2_Speed, speed);  //控制电机的速度，不同的车模，代码执行效果不同！
    analogWrite(M3_Speed, speed);  //控制电机的速度，不同的车模，代码执行效果不同！
    analogWrite(M4_Speed, speed);  //控制电机的速度，不同的车模，代码执行效果不同！
  }

  void stop() {
    digitalWrite(L1_IN1, LOW);
    digitalWrite(L1_IN2, LOW);
    digitalWrite(R1_IN1, LOW);
    digitalWrite(R1_IN2, LOW);
    digitalWrite(L2_IN1, LOW);
    digitalWrite(L2_IN2, LOW);
    digitalWrite(R2_IN1, LOW);
    digitalWrite(R2_IN2, LOW);
  }

  void backward() {
    digitalWrite(L1_IN1, HIGH);
    digitalWrite(L1_IN2, LOW);
    digitalWrite(R1_IN1, HIGH);
    digitalWrite(R1_IN2, LOW);
    digitalWrite(L2_IN1, HIGH);
    digitalWrite(L2_IN2, LOW);
    digitalWrite(R2_IN1, HIGH);
    digitalWrite(R2_IN2, LOW);
  }

  void forward() {
    digitalWrite(L1_IN1, LOW);
    digitalWrite(L1_IN2, HIGH);
    digitalWrite(R1_IN1, LOW);
    digitalWrite(R1_IN2, HIGH);
    digitalWrite(L2_IN1, LOW);
    digitalWrite(L2_IN2, HIGH);
    digitalWrite(R2_IN1, LOW);
    digitalWrite(R2_IN2, HIGH);
  }

  void right() {
    digitalWrite(L1_IN1, LOW);
    digitalWrite(L1_IN2, HIGH);
    digitalWrite(R1_IN1, HIGH);
    digitalWrite(R1_IN2, LOW);
    digitalWrite(L2_IN1, LOW);
    digitalWrite(L2_IN2, HIGH);
    digitalWrite(R2_IN1, HIGH);
    digitalWrite(R2_IN2, LOW);
  }
  
  void left() {
    digitalWrite(L1_IN1, HIGH);
    digitalWrite(L1_IN2, LOW);
    digitalWrite(R1_IN1, LOW);
    digitalWrite(R1_IN2, HIGH);
    digitalWrite(L2_IN1, HIGH);
    digitalWrite(L2_IN2, LOW);
    digitalWrite(R2_IN1, LOW);
    digitalWrite(R2_IN2, HIGH);
  }
/*
  void redo_right() {
    analogWrite(M1_Speed, 80);  //控制电机的速度，不同的车模，代码执行效果不同！
    analogWrite(M2_Speed, 140);  //控制电机的速度，不同的车模，代码执行效果不同！
    analogWrite(M3_Speed, 80);  //控制电机的速度，不同的车模，代码执行效果不同！
    analogWrite(M4_Speed, 140);  //控制电机的速度，不同的车模，代码执行效果不同！
    digitalWrite(L1_IN1, HIGH);
    digitalWrite(L1_IN2, LOW);
    digitalWrite(R1_IN1, HIGH);
    digitalWrite(R1_IN2, LOW);
    digitalWrite(L2_IN1, HIGH);
    digitalWrite(L2_IN2, LOW);
    digitalWrite(R2_IN1, HIGH);
    digitalWrite(R2_IN2, LOW);
  }

  void redo_left() {
    analogWrite(M1_Speed, 140);  //控制电机的速度，不同的车模，代码执行效果不同！
    analogWrite(M2_Speed, 80);  //控制电机的速度，不同的车模，代码执行效果不同！
    analogWrite(M3_Speed, 140);  //控制电机的速度，不同的车模，代码执行效果不同！
    analogWrite(M4_Speed, 80);  //控制电机的速度，不同的车模，代码执行效果不同！
    digitalWrite(L1_IN1, HIGH);
    digitalWrite(L1_IN2, LOW);
    digitalWrite(R1_IN1, HIGH);
    digitalWrite(R1_IN2, LOW);
    digitalWrite(L2_IN1, HIGH);
    digitalWrite(L2_IN2, LOW);
    digitalWrite(R2_IN1, HIGH);
    digitalWrite(R2_IN2, LOW);
  }
*/
  void horizontal_L() {
    digitalWrite(L1_IN1, LOW);
    digitalWrite(L1_IN2, HIGH);
    digitalWrite(R1_IN1, HIGH);
    digitalWrite(R1_IN2, LOW);
    digitalWrite(L2_IN1, HIGH);
    digitalWrite(L2_IN2, LOW);
    digitalWrite(R2_IN1, LOW);
    digitalWrite(R2_IN2, HIGH);
  }

  void horizontal_R() {
    digitalWrite(L1_IN1, HIGH);
    digitalWrite(L1_IN2, LOW);
    digitalWrite(R1_IN1, LOW);
    digitalWrite(R1_IN2, HIGH);
    digitalWrite(L2_IN1, LOW);
    digitalWrite(L2_IN2, HIGH);
    digitalWrite(R2_IN1, HIGH);
    digitalWrite(R2_IN2, LOW);
  }
};

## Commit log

2023-12-04 second commit
    [Backplate.SLDPRT, Backplate.STL, Battery backplane.SLDPRT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]
2023-12-05 third commit
    [panel.SLDPRT, panel.STL]
2023-12-05 forth commit
    [rocker.SLDPRT, rocker.STL]
2023-12-20 fix:turn and straght in the same time
    [nRF24L01-Receiver.ino, nRF24L01-Transmitter.ino]
2023-12-27 feat:add servo control
2024-01-29 add : add PCB and more models to handle smoothly
    [panel.SLDPRT, 握把.SLDPRT]
2024-02-16 fix : LCD bug
    [nRF24L01-Transmitter.ino]
